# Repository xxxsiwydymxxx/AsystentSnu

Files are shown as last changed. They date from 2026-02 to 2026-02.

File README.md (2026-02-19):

Author: Piotr Szlejter
Project name: Asystent snu, urządzenie mierzące czynniki wpływające na sen
Description:
Urządzenie składa się z 2 części komunikujących się ze sobą bezprzewodowo
urządzenie bazowe posiada czujniki temperatury, ciśnienia atmosferycznego, 
wilgotności powietrza, dodatkowo zawiera czujnik ruchu i mikrofon, dodatkowo
 urządzenie posiada wyświetlacz / możliwość połączenia się z telefonem, 
 dodatkowo urządzenie może posiadać głośnik.
	Urządzenie dodatkowe jest zakładane na nadgarstek/palec i posiada 
pulsometr, oraz czujnik nasycenia krwi tlenem.
	Działanie: urządzenie wykonuje pomiary podczas snu i wyświetla je 
na wyświetlaczu oraz zapisuje do pamięci, dodatkowo urządzenie może 
odtwarzać biały szum przez wbudowany głośnik

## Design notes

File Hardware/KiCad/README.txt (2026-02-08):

Schematy zostały wykonane w programie KiCAD

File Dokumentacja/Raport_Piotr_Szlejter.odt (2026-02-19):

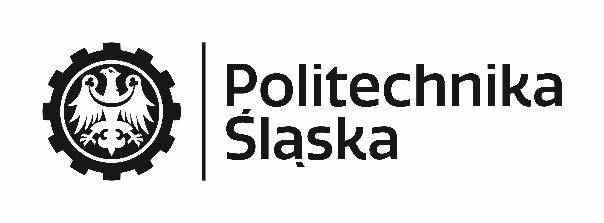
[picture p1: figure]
Obraz zawierający tekst, Czcionka, logo, Grafika Zawartość wygenerowana przez AI może być niepoprawna.
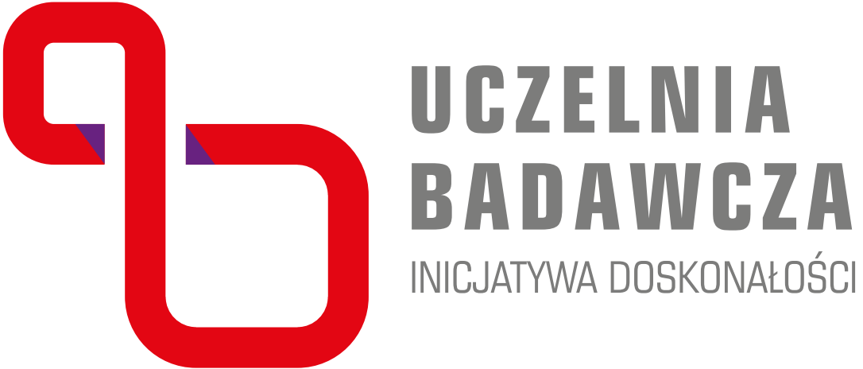
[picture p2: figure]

Raport
Rodzaj zajęć
Projekt
Przedmiot
Systemy Mikroprocesorowe i Wbudowane
Rok akademicki | | Miasto | Kierunek | | Semestr | Prowadzący | | Grupa | Sekcja
2025/2026 | | G | Inf | | 5 | GB | | 5 | 9
Planowany termin wykonywania ćwiczenia | | | | Faktyczny termin wykonania ćwiczenia
Data | | Godzina | | Data | | | Godzina
26.01.2026 | | 11:30-13:00 | | 26.01.2026 | | | 11:30-13:00
Numer ćwiczenia | Temat ćwiczenia
| Projekt – Asystent Snu

Skład sekcji
| Imię i nazwisko | Uwagi
1 | Piotr Szlejter
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
1. Temat Projektu:

Asystent Snu – urządzenie mierzące czynniki wpływające na sen.

2. Linki do repozytorium:

- https://drive.google.com/drive/folders/1vB9gLUQ3DNj9q-B88YDbHVIixlTGyozg?usp=sharing

-https://github.com/xxxsiwydymxxx/AsystentSnu.git

3. Opis założeń projektu:

- Urządzenie mierzące czynniki mające wpływ na sen.

- Urządzenie składa się z stacji bazowej, oraz nakładanego na palec, bezprzewodowego urządzenia – czujnika.

- Urządzenie mierzy: temperaturę, ciśnienie atmosferyczne, wilgotność powietrza, puls, poziom natężenia tlenu w krwi.

- Urządzenie wyświetla na bieżąco zmierzone wartości i zapisuje je na kartę microSD ze znacznikiem czasowym.

- Zestaw składa się z 2 urządzeń łączących się bezprzewodowo, zasilanie głównego urządzenia za pomocą kabla USB, urządzenia dodatkowego za pomocą akumulatora z możliwością podłączenia go do ładowania.

- Urządzenie dodatkowe zasilane przez akumulator przez czas przynajmniej 10 godzin.

- Urządzenie dodatkowe ma możliwość podłączenia do ładowania.

- Urządzenie dodatkowe ma możliwość wyłączenia się w celu nie zużywania energii.

- Urządzenie dodatkowe przesyła do urządzenia głównego rezultaty pomiarów pulsu i nasycenia tlenem krwi.

4. Analiza zadania:

Potrzebne były 2 mikrokontrolery, pełniące funkcję jednostki głównej, przetwarzającej pomiary i komunikujące się ze sobą. Ze względu na energooszczędność względem Wi-fi, i to że urządzenia będą współpracować ze sobą w obrębie jednego pomieszczenia wybrane zostały urządzenia posiadające moduł BLE – Bluetooth low energy.
Czujniki zostały dobrane tak, aby w rozsądnej kwocie mierzyły jak najwięcej czynników mogących mieć wpływ na sen.

Urządzenie dodatkowe powinno być zasilane z baterii aby ograniczyć możliwość zerwania kabla w trakcie snu, gdy czujnik przymocowany jest do palca.

4. Wybrane podzespoły:

a) urządzenie główne:

- mikrokontroler: Raspberry PI pico 2 w, wybrane z powodu niskiej ceny, możliwości Bluetooth / Wi-fi, wysokiej wydajności mikrokontrolera.

- czujniki: czujnik bme280: niska cena, możliwości pomiaru wilgotności, ciśnienia atmosferycznego oraz temperatury na jednym module.

- wyświetlacz OLED: Waveshare zgodny z sterownikiem ssd1306: wyświetlacz jest dość czytelny dla małej ilości danych, oraz był już dostępny w zasobach własnych.

- czytnik kart microSD: najtańszy model dostępny w sklepie Botland komunikujący się przez SPI.

- Moduł RTC: HW-111: moduł pozwoli na zapisywanie danych na kartę microSD ze znacznikiem czasowym.

b) urządzenie dodatkowe:

- mikrokontroler: Seeed xiao NRF52840: wybrany ze względu na wbudowaną ładowarkę baterii, możliwości łączenia się przez bluetooth, oraz niski pobór mocy.

- czujnik tętna: M5stack heart MAX30100: wybrany ze względu na gotową obudowę i możliwość odczytu tętna i nasycenia tlenem krwi.

- akumulator li-pol akyga 900 mAh

5. Specyfikacja wewnętrzna:

a) Schematy blokowe i ideowe

- urządzenie główne schemat blokowy:

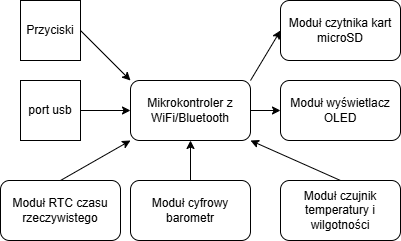
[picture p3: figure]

- urządzenie główne schemat ideowy:

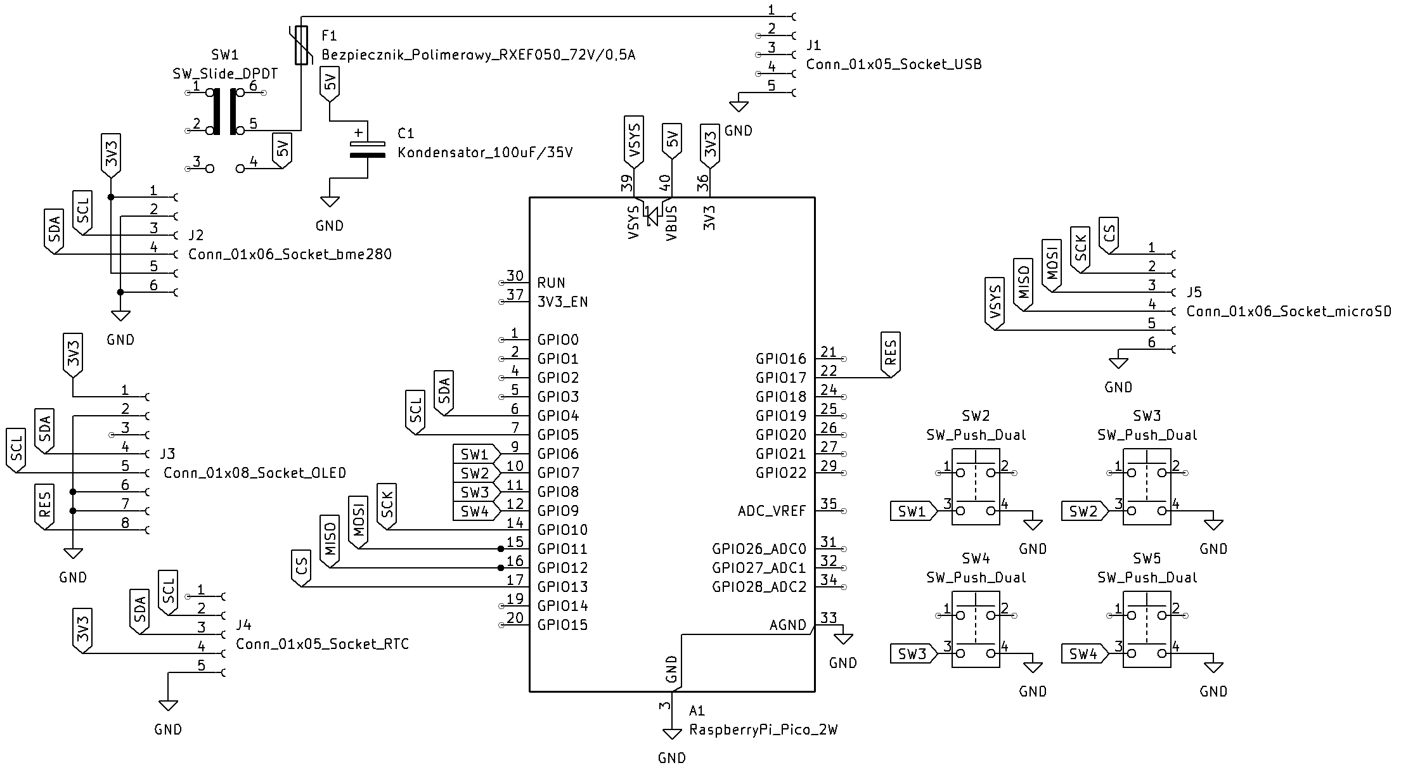
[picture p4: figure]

- urządzenie dodatkowe schemat blokowy:

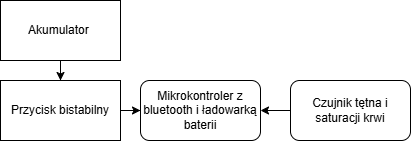
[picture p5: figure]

- urządzenie dodatkowe schemat ideowy:

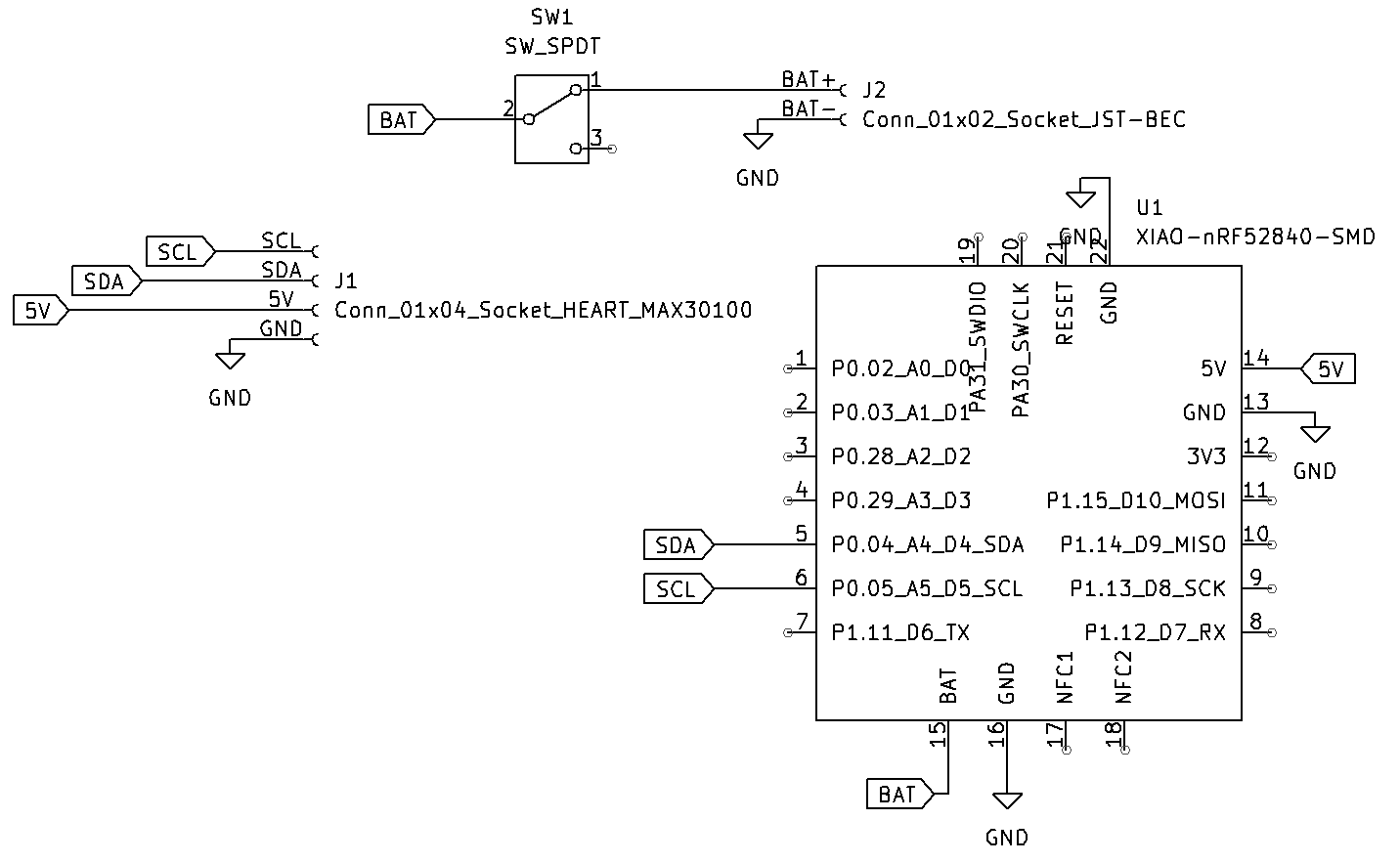
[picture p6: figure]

b) Opis funkcji poszczególnych bloków układu:

- urządzenie główne:

Blok Przyciski: przyciski tactile switch podłączone od portu do masy.

Blok port USB: zewnętrzny port USB pozwalający dostarczyć zasilanie, z możliwością wyłączenia urządzenia przyciskiem.

Blok mikrokontrolera: mikrokontroler Raspberry pi pico 2w, zasilany przez pin Vbus z portu USB.

Blok moduł RTC: moduł RTC z baterią CR2032, dzięki baterii przechowuje zapisany czas przy wyłączonym urządzeniu, baterię należy wymienić co ok 10 lat.

Blok moduł czytnika kart microSD: połączony przez SPI moduł pozwalający dołączyć kartę microSD sformatowaną w formacie fat32.

Blok moduł wyświetlacz OLED: wyświetlacz z możliwością komunikowania się przez i2c lub SPI, skonfigurowany przez przelutowanie rezystora na komunikację po i2c. Wymaga podłączenia pinu reset do portu GPIO mikrokontrolera.

Blok moduł czujnik temperatury i wilgotności: moduł BME280, komunikuje się przez i2c. Wynik ciśnienia atmosferycznego nie jest ustandaryzowany do poziomu morza.

- urządzenie dodatkowe:

Blok mikrokontrolera: Seeed Xiao NRF52840, energooszczędny mikrokontroler, mogący komunikować się poprzez bluetooth, do jego pinów BAT+ i BAT- przylutowany został przewód do akumulatora/

Blok czujnik tętna i saturacji krwi: m5stack heart max 30100, czujnik działa przez podświetlenie diodą podczerwoną palca, lub nadgarstka, i przez czujnik monitorujące tętno i saturację tlenem krwi. Aby mierzyć tętno w nadgarstku trzeba konfigurując czujnik, ustawić zasilanie diody na większe niż domyślne 7,6 mA dla palca, ponieważ nie wystarcza wtedy światła aby przebić skórę. Dla palca natomiast ustawienie 7.6 mA w zupełności wystarcza i większy prąd powoduje że czujnik jest przejaskrawiony i niepoprawnie odczytuje pomiar.

c) Schemat montażowy obejmujący projekt płytki drukowanej, rozmieszczenie elementów na płytce, rozmieszczenie elementów urządzenia w obudowie:

- urządzenie główne:

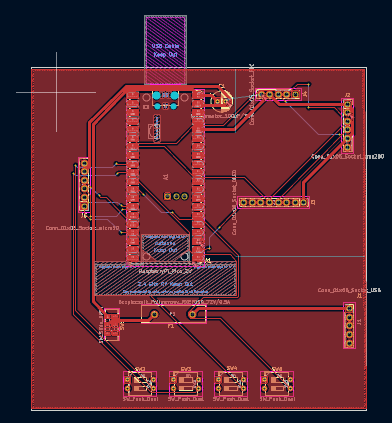
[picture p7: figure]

- urządzenie dodatkowe nie wymaga płytki drukowanej ponieważ składa się jedynie z mikrokontrolera, gotowego przyłącza baterii na nim i 1 czujnika z gotową obudową.

d) Algorytm oprogramowanie urządzenia:

- urządzenie główne:

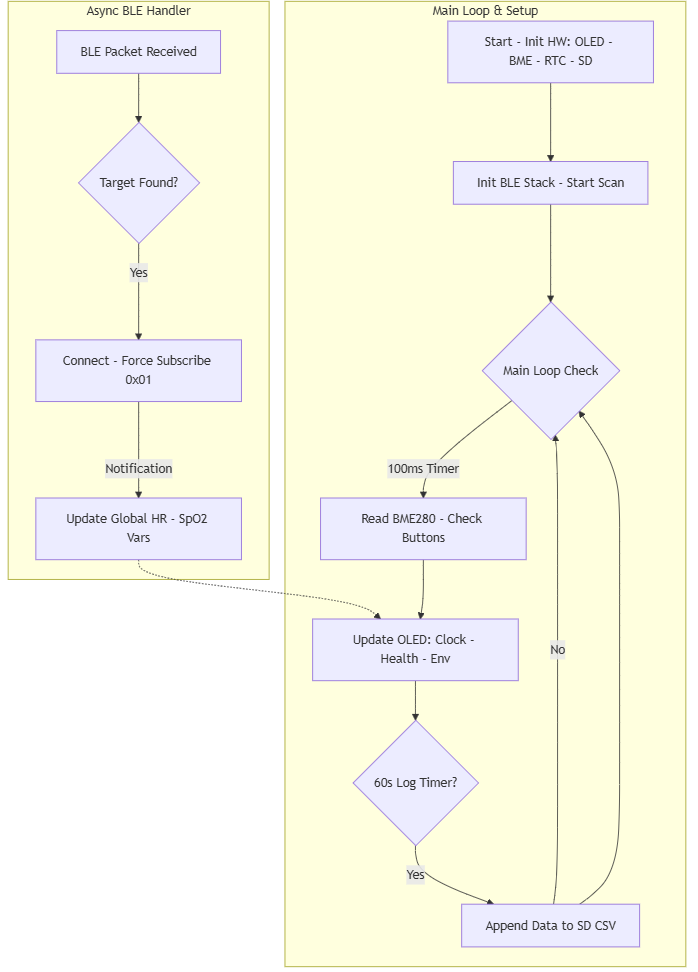
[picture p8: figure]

- urządzenie dodatkowe:

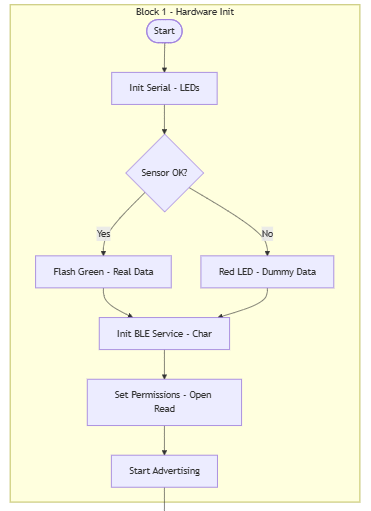
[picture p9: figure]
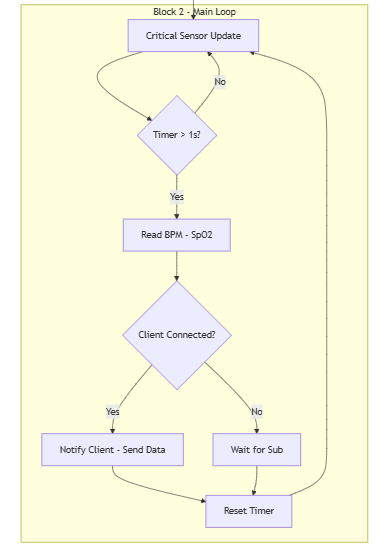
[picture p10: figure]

e) Opis wszystkich zmiennych:

- urządzenie główne:

zmienne potrzebne dla bluetooth:

const char* target_name = "XIAO_Health_Native";

const uint16_t target_service_uuid = 0xFF00;

const uint16_t target_char_uuid = 0xFF01;

static btstack_packet_callback_registration_t hci_event_callback_registration;

static hci_con_handle_t connection_handle = HCI_CON_HANDLE_INVALID;

static gatt_client_notification_t notification_listener;

static gatt_client_service_t found_service;

static gatt_client_characteristic_t found_char;

static bool service_found = false;

static bool char_found = false;

static bool is_subscribed = false;

zmienne potrzebne dla wyświetlania wartości przesłanych przez bluetooth:

volatile int global_hr = 0;

volatile int global_spo2 = 0;

bool bleConnected = false;

zmienne potrzebne dla podłączonych czujników, wyświetlacza i przycisków:

// --- HARDWARE SETTINGS ---

// 1. I2C

#define I2C_SDA_PIN 4

#define I2C_SCL_PIN 5

#define OLED_RESET 17

// 2. SPI1

#define SD_SCK 10

#define SD_MOSI 11

#define SD_MISO 12

#define SD_CS 13

// 3. BUTTONS

#define BTN1_PIN 6

#define BTN2_PIN 7

#define BTN3_PIN 8

#define BTN4_PIN 9

#define BME_ADDR 0x76

#define OLED_ADDR 0x3C

Adafruit_SSD1306 display(128, 64, &Wire, OLED_RESET);

Adafruit_BME280 bme;

RTC_DS3231 rtc;

uint32_t tsLastReport = 0;

uint32_t tsLastLog = 0;

const long REPORT_PERIOD = 100;

const long LOG_PERIOD = 60000;

bool sdStatus = false;

int currentMode = 1;

- urządzenie dodatkowe:

wbudowane LED:

#define LEDR 11

#define LEDG 12

#define LEDB 13

zmienne przechowujące dane z czujnika:

PulseOximeter pox;

uint32_t tsLastReport = 0;

bool sensorWorking = false;

zmienne potrzebne dla bluetooth:

const uint16_t CUSTOM_SERVICE_UUID = 0xFF00;

const uint16_t CUSTOM_CHAR_UUID = 0xFF01;

BLEService customService = BLEService(CUSTOM_SERVICE_UUID);

BLECharacteristic customChar = BLECharacteristic(CUSTOM_CHAR_UUID);

f) Opis funkcji wszystkich procedur:

- urządzenie główne:

void setup();

Funkcja inicjalizuje oprogramowanie.

void loop();

Główna pętla programu.

void logData(DateTime dt, float t, float h, float p, int hr, int spo2);

Funkcja logujące dane do karty microSD

void updateScreen(DateTime now, float t, float h, float p, bool sdOk, int mode);

Funkcja wyświetlająca dane na wyświetlacz OLED.

static void packet_handler(uint8_t packet_type, uint16_t channel, uint8_t *packet, uint16_t size);

Jest to główna funkcja zarządzająca stanami Bluetooth, która odpowiada za skanowanie otoczenia, łączenie się z wykrytym urządzeniem "XIAO_Health_Native" oraz ponowne uruchamianie skanowania po rozłączeniu .

static void gatt_event_handler(uint8_t packet_type, uint16_t channel, uint8_t *packet, uint16_t size);

Funkcja ta odbiera przychodzące powiadomienia - notyfikacje z danymi i wpisuje odebrane wartości tętna oraz SpO2 do zmiennych globalnych .

static void on_characteristics_discovered(uint8_t packet_type, uint16_t channel, uint8_t *packet, uint16_t size);

Weryfikuje znalezienie szukanej charakterystyki - 0xFF01 i po jej wykryciu wymusza subskrypcję powiadomień poprzez ręczny zapis wartości 0x01 do deskryptora .

static void on_services_discovered(uint8_t packet_type, uint16_t channel, uint8_t *packet, uint16_t size);

Sprawdza, czy połączone urządzenie posiada właściwą usługę – 0xFF00 i jeśli tak, uruchamia proces wyszukiwania w niej charakterystyk .

- urządzenie dodatkowe:

void onBeatDetected()

Funkcja załączający LEDy po wykryciu tętna.

void setup()

Funkcja inicjalizująca.

void loop()

Główna pętla programu.

g) Opis interakcji oprogramowania z układem elektronicznym:

- urządzenie główne:

Oprogramowanie steruje magistralą I2C w celu inicjalizacji i komunikacji z wyświetlaczem OLED oraz czujnikami środowiskowymi BME280 i modułem czasu rzeczywistego DS3231 . Kod cyklicznie monitoruje cyfrowe wejścia podłączone do czterech przycisków fizycznych i na ich podstawie zmienia tryb prezentacji danych na ekranie . System zarządza również magistralą SPI do obsługi karty pamięci SD na której regularnie zapisuje logi z danymi pomiarowymi w pliku tekstowym . Równolegle stos Bluetooth Low Energy pracuje w trybie centralnym skanując otoczenie w poszukiwaniu czujnika medycznego i po nawiązaniu połączenia odbiera od niego pakiety danych .

- urządzenie dodatkowe:

Program obsługuje czujnik pulsoksymetru MAX30100 poprzez magistralę I2C i wykonuje w głównej pętli krytyczne czasowo operacje przetwarzania sygnału biometrycznego. Mikrokontroler steruje diodami LED RGB sygnalizując kolorem zielonym poprawną pracę sensora lub czerwonym błąd inicjalizacji i przejście w tryb generowania danych testowych . Oprogramowanie uruchamia stos Bluetooth w trybie peryferyjnym rozgłaszając dedykowaną usługę i po otrzymaniu żądania subskrypcji wysyła do urządzenia nadrzędnego powiadomienia z aktualnym tętnem i nasyceniem tlenem .

h) Szczegółowy opis ważniejszych procedur:

- urządzenie główne:

static void packet_handler(uint8_t packet_type, uint16_t channel, uint8_t *packet, uint16_t size);

Jest to główna funkcja zarządzająca stanami Bluetooth, która odpowiada za skanowanie otoczenia, łączenie się z wykrytym urządzeniem "XIAO_Health_Native" oraz ponowne uruchamianie skanowania po rozłączeniu .

static void gatt_event_handler(uint8_t packet_type, uint16_t channel, uint8_t *packet, uint16_t size);

Funkcja ta odbiera przychodzące powiadomienia - notyfikacje z danymi i wpisuje odebrane wartości tętna oraz SpO2 do zmiennych globalnych .

static void on_characteristics_discovered(uint8_t packet_type, uint16_t channel, uint8_t *packet, uint16_t size);

Weryfikuje znalezienie szukanej charakterystyki - 0xFF01 i po jej wykryciu wymusza subskrypcję powiadomień poprzez ręczny zapis wartości 0x01 do deskryptora .

static void on_services_discovered(uint8_t packet_type, uint16_t channel, uint8_t *packet, uint16_t size);

Sprawdza, czy połączone urządzenie posiada właściwą usługę – 0xFF00 i jeśli tak, uruchamia proces wyszukiwania w niej charakterystyk .

- urządzenie dodatkowe:

void loop()
Główna pętla programu nieustannie wywołuje metodę aktualizacji obiektu pulsoksymetru o ile flaga stanu sensora jest aktywna co pozwala na precyzyjne śledzenie uderzeń serca w czasie rzeczywistym. Co jedną sekundę kod sprawdza licznik czasu i pobiera bieżące wartości tętna oraz nasycenia krwi tlenem lub w przypadku awarii sprzętu podstawia sztywne wartości testowe wynoszące odpowiednio 65 BPM i 98 procent . Następnie procedura weryfikuje stan połączenia Bluetooth i jeśli klient jest połączony oraz aktywował subskrypcję powiadomień to wysyła dwubajtowy pakiet danych do urządzenia centralnego . W przypadku braku aktywnej subskrypcji lub po wysłaniu danych program wypisuje odpowiednie komunikaty diagnostyczne na port szeregowy i resetuje licznik czasu w celu odmierzenia kolejnego cyklu pomiarowego .

5. Specyfikacja zewnętrzna:

a) Opis funkcji elementów sterujących urządzeniem:

- urządzenie główne:

Przyciski tactile switch przełączają urządzenie między czterema różnymi wyświetlanymi ekranami, na 1 znajduje się data i godzina, na 2 znajdują się pomiary z urządzenia dodatkowego przesłane przez bluetooth, na 3 znajdują się wszystkie pomiary na jednym ekranem łącznie z temperaturą, wilgotnością i ciśnieniem, na 4 ekranie nie wyświetla się nic, służy on jako zgaszony ekran i tylko zapisuje na kartę microSD w tle.

Przełącznik suwakowy pozwala na włączenie i wyłączenie urządzenia.

-urządzenie dodatkowe:

Przycisk bistabilny pozwala na włączenie i wyłączenie urządzenia, nie będzie on działał gdy urządzenie podłączymy przez port usb typu C do ładowania.

b) Opis funkcji elementów wykonawczych:

- urządzenie główne:

Wyświetlacz OLED wyświetla 4 różne ekrany opisane zawierające różne dane z czujników.

Moduł kart microSD pozwala na włożenie karty microSD, i zapisywanie na nią pomiarów wraz z znacznikiem czasowym z modułu RTC.

c) Opis reakcji oprogramowania na zdarzenia zewnętrzne:

- urządzenie główne:

Po włączeniu urządzenia wykonuje ono próbę połączenia się przez bluetooth, gdy w pobliżu znajduje się urządzenie dodatkowe włączone, to urządzenia nawiążą połączenie, następuje również inicjalizacja modułu kart microSD, jeśli się nie powiedzie wyświetli się na ekranie komunikat.

Po przyciśnięciu przycisku urządzenie reaguje przełączajać tryb pracy – zawartość wyświetlaną na ekranie.

- urządzenie dodatkowe:

urządzenie włączy się po przyciśnięciu przycisku bistabilnego, i zacznie propagację siebie w sieci bluetooth, sygnalizując to diodą LED, po połączeniu dioda LED zgaśnie, po przyłożeniu palca do czujnika m5stack Heart max 30100, dioda LED zapali się po wykryciu pulsu.

d) Skrócona instrukcja obsługi urządzenia:

Urządzenie główne należy włączyć do zasilania 5V min 1A przez port micro USB dodatkowy z boku urządzenia, nie ten wbudowany w Raspberry pi pico 2w, po włączeniu można wybrać tryb pracy przyciskając odpowiedni przycisk.

Urządzenie dodatkowe należy wyłączać przyciskiem bistabilnym, można je również podłączyć do ładowania przez wbudowany w Seeed Xiao port USB typu C.

Aby połączyć urządzenia należy najpierw włączyć urządzenie dodatkowe, a później włączyć urządzenie główne, połączenie nastąpi automatycznie.

6. Opis montażu i uruchamiania:

a) Jakie problemy wystąpiły podczas montażu i uruchamiania i jak zostały rozwiązane.

- Problem z wyświetlaczem OLED: wyświetlacz OLED zdawał się nie działać, nie wyświetlał nic, po podłączeniu pinu RES z wyświetlacza do portu GPIO pico i odpowiedniej obsłudze programowej wyświetlacz zaczął działać

- Problemy z połączeniem bluetooth, urządzenie główne z raspberry pi pico 2 w, zdawało się nie działać, łączyło się po bluetooth ale nie pobierało danych przesyłanych, podobnie po skonfigurowaniu jako serwer i połączeniu po bluetooth z telefonem, testowano z użyciem apki NRF connect, nie transmitowało danych. Problem występował przy użyciu bilbioteki bluetooth Adafruit. Problem został rozwiązany po przejściu na wspieraną przez raspberry pi pico bibliotekę bluetooth btstack.h

- Głównym problemem była niemożność automatycznego odnalezienia przez Pico właściwego adresu sterującego w pamięci Bluetooth urządzenia XIAO. Standardowa funkcja biblioteki BTstack gubiła się przy próbie zapisu do deskryptora konfiguracji, co uniemożliwiało włączenie powiadomień o nowych danych. Dodatkowo kod na XIAO miał zbyt restrykcyjne ustawienia uprawnień, które blokowały próby zapisu ze strony niesparowanego urządzenia takiego jak Pico. Skutkowało to sytuacją, w której XIAO próbowało wysyłać dane w próżnię otrzymując błąd transmisji, podczas gdy Pico czekało w nieskończoność na potwierdzenie subskrypcji. Rozwiązanie polegało na obejściu automatycznego wyszukiwania i ręcznym wyliczeniu adresu sterującego poprzez dodanie jedynki do adresu charakterystyki głównej. Dzięki temu mogliśmy wysłać surową komendę aktywacyjną bezpośrednio pod wskazany adres ignorując standardowe procedury negocjacji. Równocześnie zmodyfikowaliśmy kod nadajnika, aby zezwalał na otwarty dostęp do zapisu i wstrzymywał wysyłanie pomiarów do momentu poprawnego zestawienia połączenia.

b) Jakie przeprowadzono testy poprawności działania urządzenie:

Przeprowadzono testy łączności w obrębie jednego pomieszczenia, przeprowadzono testy poszczególnych komponentów łącząc je tylko z mikrokontrolerem i wgrywając testowy kod.

Przeprowadzono obszerne testy łączności bluetooth z różnymi wersjami kodu łączacymi się z telefonem – aplikacją NRF Connect, lub ze sobą i wypisujące na Serial monitor.

7. Wnioski z uruchamiania i testowania:

- Podczas testowania wyszedł problem w urządzeniu dodatkowym polegający na tym że urządzenie dodatkowe po zasileniu z baterii 3,7 V, nie ustawia zasilania 5v na pinie 5V, przez co urządzenie m5stack Heart max 30100 nie włączało się ponieważ mimo logiki 3,3V urządzenie to jest zasilane z 5V, problem ten można by rozwiązać kupując droższy czujnik oparty na module max 30102, pracujący na zasilaniu 3,3 V. Rozwiązano ten problem przez zasilenie urządzenia przez kabel usb z powerbanka, niestety powoduje to konieczność użycia kabla, i lepszym rozwiązaniem byłoby kupienie droższego czujnika, ponieważ mógłby on być uruchomiony przy zasilaniu z baterii.

- Kluczowym wyzwaniem programistycznym okazała się obsługa stosu Bluetooth Low Energy na mikrokontrolerze Raspberry Pi Pico 2 W który miał problemy z automatycznym wykrywaniem deskryptorów urządzenia podrzędnego

-W obecnej konfiguracji część mobilna wymaga zasilania przewodowego USB co ogranicza komfort użytkowania podczas snu i wymusza w przyszłości wymianę sensora na model kompatybilny z napięciem 3.3V

- Mimo problemów z zasilaniem zrealizowano główny cel projektu jakim jest integracja pomiarów środowiskowych i biometrycznych oraz ich archiwizacja na karcie microSD z wykorzystaniem znacznika czasu .

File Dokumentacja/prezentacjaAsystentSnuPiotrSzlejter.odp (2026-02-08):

## Asystent Snu

Projekt - Systemy Mikroprocesorowe i Wbudowane

## Projekt Asystent Snu

- Urządzenie mierzące czynniki mające wpływ na sen.
- Urządzenie składa się z stacji bazowej, oraz nakładanego na palec, bezprzewodowego urządzenia - czujnika

## Założenia projektowe

- Urządzenie mierzy: temperaturę, ciśnienie atmosferyczne, wilgotność powietrza, puls, poziom natężenia tlenu w krwi.
- Urządzenie wyświetla na bieżąco zmierzone wartości i zapisuje je na kartę microSD ze znacznikiem czasowym.
- Zestaw składa się z 2 urządzeń łączących się bezprzewodowo, zasilanie głównego urządzenia za pomocą kabla USB, urządzenia dodatkowego za pomocą akumulatora z możliwością podłączenia go do ładowania.

## Założenia – urządzenie dodatkowe

- Urządzenie zasilane przez akumulator przez czas przynajmniej 10 godzin.
- Urządzenie ma możliwość podłączenia do ładowania.
- Urządzenie ma możliwość wyłączenia się w celu nie zużywania energii.
- Urządzenie przesyła do urządzenia głównego rezultaty pomiarów pulsu i nasycenia tlenem krwi.

## Schematy blokowe

## Schemat blokowy – urządzenie główne

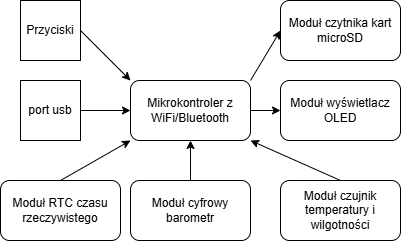
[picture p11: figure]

## Schemat blokowy – urządzenie dodatkowe


## Wybór komponentów

## Urządzenie główne

- Mikrokontroler – Raspberry Pi pico 2 W
- Czujnik wilgotności, temperatury ciśnienia – BME280
- Wyświetlacz OLED 128x64px SSD1306 – Waveshare 9092
- Moduł RTC I2C – HW-111

## Urządzenie dodatkowe

- Mikrokontroler – Seeed Xiao BLE nRF52840.
- Czujnik tętna i saturacji krwi – M5Stack Heart MAX30100.
- Akumulator – Li-Pol Akyga 900 mAh 3,7V złącze JST-BEC.

## Dobór akumulatora

- Założenie – przynajmniej 10h pracy na akumulatorze.
- Suma szczytowych poborów mocy: 90-150 mA.
- 90*10h, 150 * 10h.
- Wynik: od 900 mAh do 1500 mAh.

## Schematy ideowe

## Urządzenie główne

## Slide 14


## Urządzenie dodatkowe

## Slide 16


## Płytka drukowana

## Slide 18


## Kosztorys

## Urządzenie główne

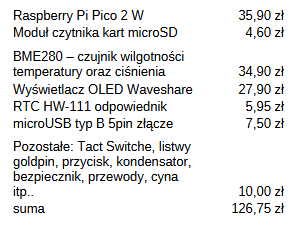
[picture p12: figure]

## Urządzenie dodatkowe

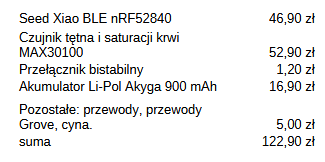
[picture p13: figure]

## Kosztorys

## Wnioski

- Urządzenie dodatkowe zawiera tylko niezbędne elementy: akumulator, czujniki biometryczne i mikrokontroler z łącznością bluetooth. Dzięki temu opaska może być mniejsza i działać dłużej na baterii.
- Urządzenie główne przejmuje cięższe zadania. Obsługuje WiFi, zapis danych na kartę SD, wyświetlacz OLED oraz pomiary środowiskowe. Dzięki czemu mamy więcej danych o czynnikach wpływających na sen.

## Wnioski

- Koszt urządzenia wyniósł prawie 250 zł co jest dość dużą kwotą, można oszczędzić na urządzeniu kupując je hurtowo, a nie poprzez detaliczny sklep Botland.
- Dalsze usprawnienie urządzenia można zrealizować poprzez zamianę czujnika bme280 na droższy bme680, lub poprzez dodanie np.. czujników VOC, lub czujniki pyłów.

## Dziękuję za uwagę

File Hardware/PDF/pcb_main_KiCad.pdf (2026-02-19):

19.02.2026, 04:02 | pcb.PNG (392×423)


file:///C:/Users/HP/Desktop/polsl/SMiW/projekt/różne/pcb.PNG | 1/1

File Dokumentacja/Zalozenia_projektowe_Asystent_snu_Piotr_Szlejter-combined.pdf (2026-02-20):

`

| Katedra Grafiki Wizji Komputerowej i Systemów Cyfrowych | RAu6
Rok akademicki: | Rodzaj studiów*: SSI/NSI/NSM | Przedmiot (J zyki ę Asemblerowe/SMiW): | Grupa | Sekcja
2025/202 6 | SSI | SMiW | 5 | 9
Imi : ę Nazwisko: | Piotr | Prowadz cy ą : OA/JP/KT/GD/ GB/KH/AO | GB
| Szlejter

# Karta projektu SMIW

Temat projektu:

Asystent snu – urządzenie mierzące czynniki wpływające na sen

Główne zało enia projektu: ż

Urządzenie składa się z 2 części komunikujących się ze sobą bezprzewodowo urządzenie bazowe posiada czujniki temperatury, ciśnienia atmosferycznego, wilgotności powietrza, dodatkowo zawiera czujnik ruchu i mikrofon, dodatkowo urządzenie posiada wyświetlacz / możliwość połączenia się z telefonem, dodatkowo urządzenie może posiadać głośnik.
Urządzenie dodatkowe jest zakładane na nadgarstek/palec i posiada pulsometr, oraz czujnik nasycenia krwi tlenem.
Działanie: urządzenie wykonuje pomiary podczas snu i wyświetla je na wyświetlaczu oraz zapisuje do pamięci, dodatkowo urządzenie może odtwarzać biały szum przez wbudowany głośnik

Temat: Asystent Snu – urządzenie mierzące czynniki wpływające na sen
Autor: Piotr Szlejter

Założenia: Urządzenie składa się z 2 części komunikujących się ze sobą bezprzewodowo urządzenie bazowe posiada czujniki temperatury, ciśnienia atmosferycznego, wilgotności powietrza, dodatkowo zawiera czujnik ruchu i mikrofon, jak również wyświetlacz / możliwość połączenia się z telefonem. Do zapisywania pomiarów i nagrań dźwięku urządzenie będzie posiadać moduł czytnika kart microSD, wraz z kartą microSD.
Urządzenie dodatkowe jest zakładane na nadgarstek/palec i posiada pulsometr, oraz czujnik nasycenia krwi tlenem i jest zasilane akumulatorem aby nie było wystąpiła sytuacja zerwania kabla mimowolnym ruchem podczas snu.

Schemat głównego urządzenia:

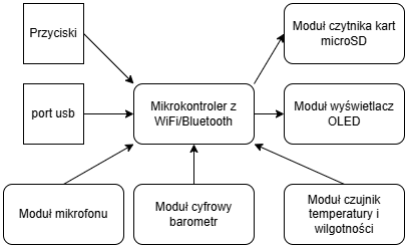
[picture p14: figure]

Schemat urządzenia dodatkowego:

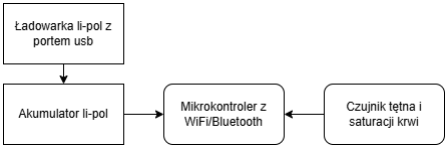
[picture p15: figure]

Mikrokontroler: Po dokonaniu rozpoznania na rynku, zdecydowałem się na użycie mikrokontrolera Raspberry Pi Pico 2 W, ze względu na jego niską cenę, możliwości WiFi/Bluetooth, oraz szerokie wsparcie producenta i społeczność internetową.

Zasilanie urządzenia głównego: zasilanie odbędzie się poprzez port USB, zasilaczem może być ładowarka do telefonu, lub komputer potrafiący dostarczyć 5V 1A.

Zużycie zasilania (maksymalny pobierany prąd):
Komponent: | Maksymalne zużycie prądu [mA]:
Raspberry Pi Pico 2 W | 300

Wyświetlacz OLED | 25
Czujnik temperatury i wilgotności - Sensirion SHT40 | 0,0004
BMP280 - cyfrowy barometr | 0,0027
czytnik kart microSD - Waveshare 3947 | 200
Moduł z mikrofonem LM393 M5stack | 23,53
Razem: | 548,53

Łączne maksymalny prąd pobierany(525 mA) nie przekracza maksymalnego prądu jaki jest w stanie dostarczyć zasilacz USB (5V 1A).

Zasilanie urządzenia dodatkowego: Zasilanie urządzenia dodatkowego będzie zrealizowane przez akumulator li-pol.

Zużycie zasilania (maksymalny pobierany prąd):

Komponent: | Maksymalne zużycie prądu [mA]:
Raspberry Pi Pico 2 W | 300
Czujnik tętna i saturacji krwi MAX30100 | 0,6
| 300,6

Obliczenia pojemności akumulatora: Typowy pobór prądu przez Raspberry Pi Pico 2 W przy używaniu WiFi to 90–150 mA co oznacza że żeby bateria wytrzymała użycie przez 10h należy wybrać akumulator o pojemności:
od 90mA×10h=900mAh
do 150mA×10h=1500mAh

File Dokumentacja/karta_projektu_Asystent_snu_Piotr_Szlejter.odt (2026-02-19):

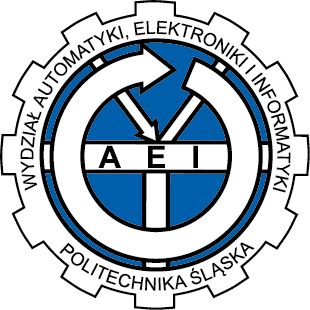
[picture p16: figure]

Katedra Grafiki Wizji Komputerowej i Systemów Cyfrowych RAu6 Rok akademicki: Rodzaj studiów*: SSI/NSI/NSM Przedmiot (Języki Asemblerowe/SMiW): Grupa Sekcja 2025/2026 SSI SMiW 5 9 Imię: Piotr Prowadzący: OA/JP/KT/GD/GB/KH/AO GB Nazwisko: Szlejter Karta projektu SMIW Temat projektu: Asystent snu – urządzenie mierzące czynniki wpływające na sen Główne założenia projektu: Urządzenie składa się z 2 części komunikujących się ze sobą bezprzewodowo urządzenie bazowe posiada czujniki temperatury, ciśnienia atmosferycznego, wilgotności powietrza, dodatkowo zawiera czujnik ruchu i mikrofon, dodatkowo urządzenie posiada wyświetlacz / możliwość połączenia się z telefonem, dodatkowo urządzenie może posiadać głośnik. Urządzenie dodatkowe jest zakładane na nadgarstek/palec i posiada pulsometr, oraz czujnik nasycenia krwi tlenem. Działanie: urządzenie wykonuje pomiary podczas snu i wyświetla je na wyświetlaczu oraz zapisuje do pamięci, dodatkowo urządzenie może odtwarzać biały szum przez wbudowany głośnik Data oddania: dd/mm/rrrr 19.02.2026 `

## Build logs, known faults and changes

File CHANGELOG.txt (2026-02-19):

Date: 19.02.2026

current_version
main: v2.5
secondary: v1.5

Version history:

Urządzenie główne:
v1.0
	test z modułem bme280
v1.1
	test z samym modułem RTC
v1.2
	test z modułem RTC i bme280
v1.3
	test z modułem microSD card
v1.4
	test z modułem heart max30100
v1.5
	test z mikrofonem
v1.6
	test z modułem bme280 i wyświetlaczem oled
v1.7
	test z modułami 280, oled, m5heart max30100
v1.8
	test z modułami bme 280, oled, microSD card
v1.9
	test z modułami bme 280, oled, microSD card, 4 switches
v2.0
	test BLE
v2.1
	test BLE z zamianą ról urządzeń
v2.2
	test połączenia z telefonem
v2.3
	test z biblioteką btstack.h
v2.4
	test z biblioteką ArduinoBLE z modułami bme280, oled, microSD card, RTC, 4 switch
v2.5
	test z biblioteką btstack.h z modułami oled, microSD card, bme280, RTC, 4 switch

Urządzenie dodatkowe:
v1.0
	test blink sketch
v1.2
	test blink z modułem heart m5stack max30100
v1.3
	test z ArduinoBLE
v1.4
	test połączenia z telefonem
v1.5
	test z ArduinoBLE z modułem m5stack heart max30100

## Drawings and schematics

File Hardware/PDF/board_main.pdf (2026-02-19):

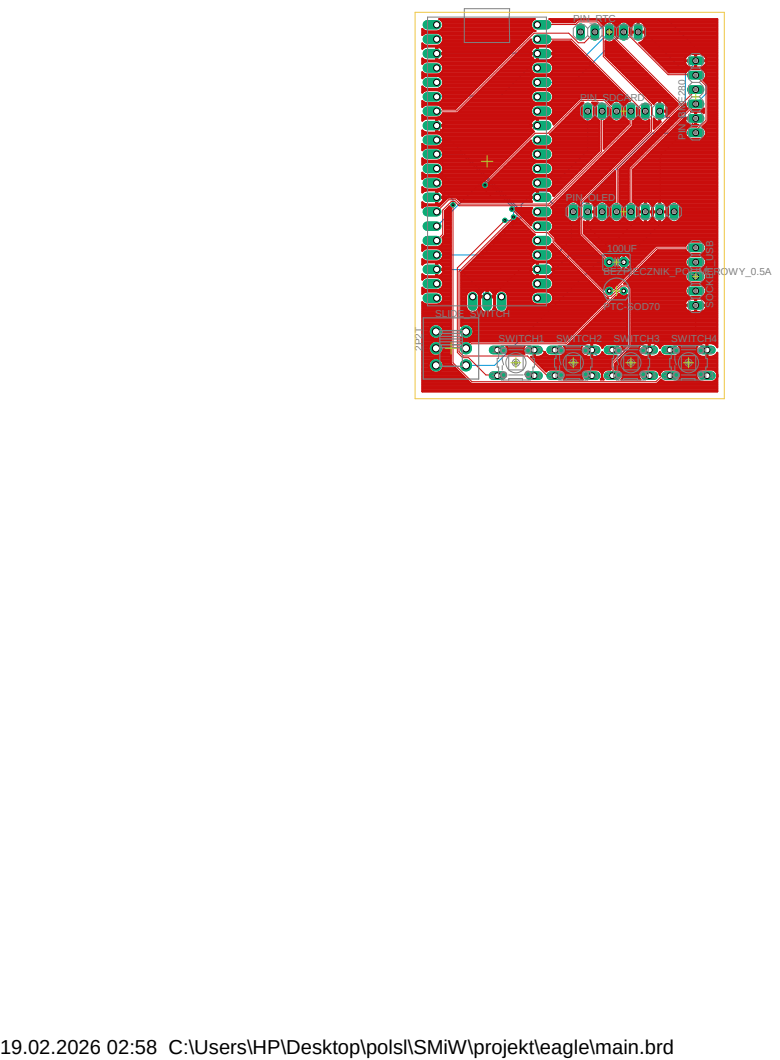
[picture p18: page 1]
BEZPIECZNIK_POLIMEROWY_0.5A PIN_BME²⁸⁰; PIN_OLED; PIN_RTC; PIN_SDCARD; SLIDE_SWITCH; SOCKET_USB; SWITCH1 SWITCH2 SWITCH3 SWITCH4; PTC-SOD70 2P²T

19.02.2026 02:58 C:\Users\HP\Desktop\polsl\SMiW\projekt\eagle\main.brd

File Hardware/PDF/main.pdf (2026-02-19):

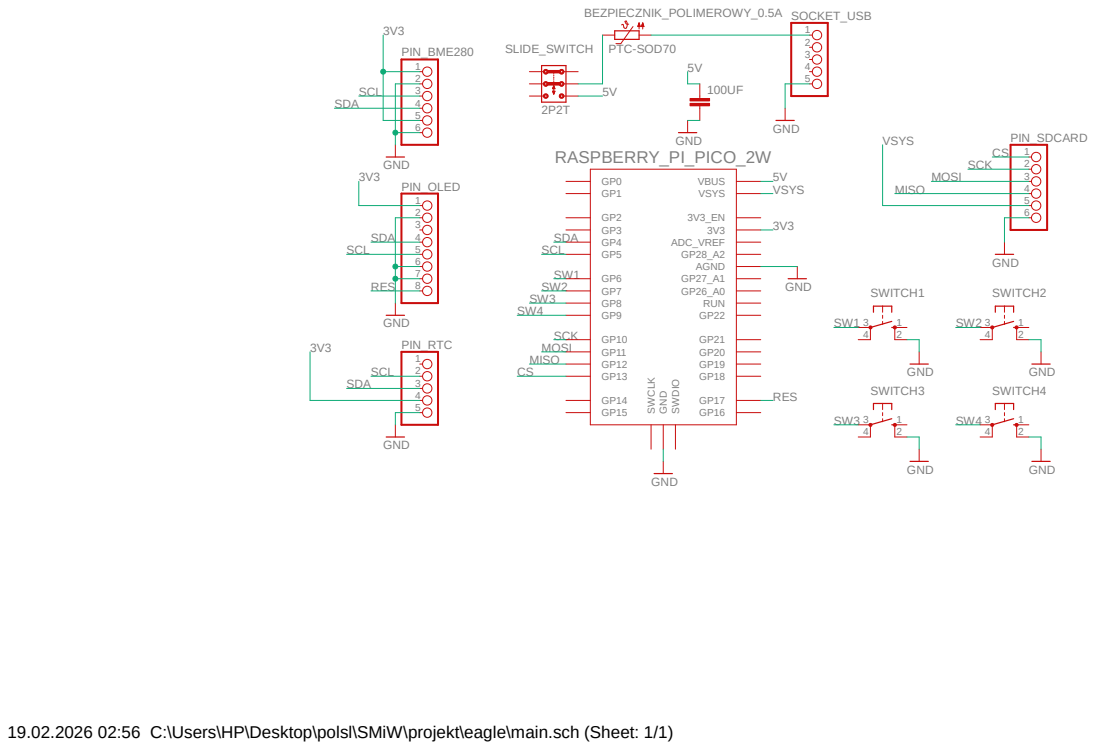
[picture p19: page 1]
GND; PTC-SOD70; RUN; AGND; ADC_VREF; VSYS; VBUS SWCLK GND SWDIO; RASPBERRY_PI_PICO_2W; 6 PIN_BME280; 8 PIN_OLED; 5 PIN_RTC; 6 PIN_SDCARD; SLIDE_SWITCH; 5 BEZPIECZNIK_POLIMEROWY_0.5A SOCKET_USB; 4 2 SWITCH1; 4 2 SWITCH2; 4 2 SWITCH3; 4 2 SWITCH4; SDA; SCL; SCK; MOSI; MISO; RES

19.02.2026 02:56 C:\Users\HP\Desktop\polsl\SMiW\projekt\eagle\main.sch (Sheet: 1/1)

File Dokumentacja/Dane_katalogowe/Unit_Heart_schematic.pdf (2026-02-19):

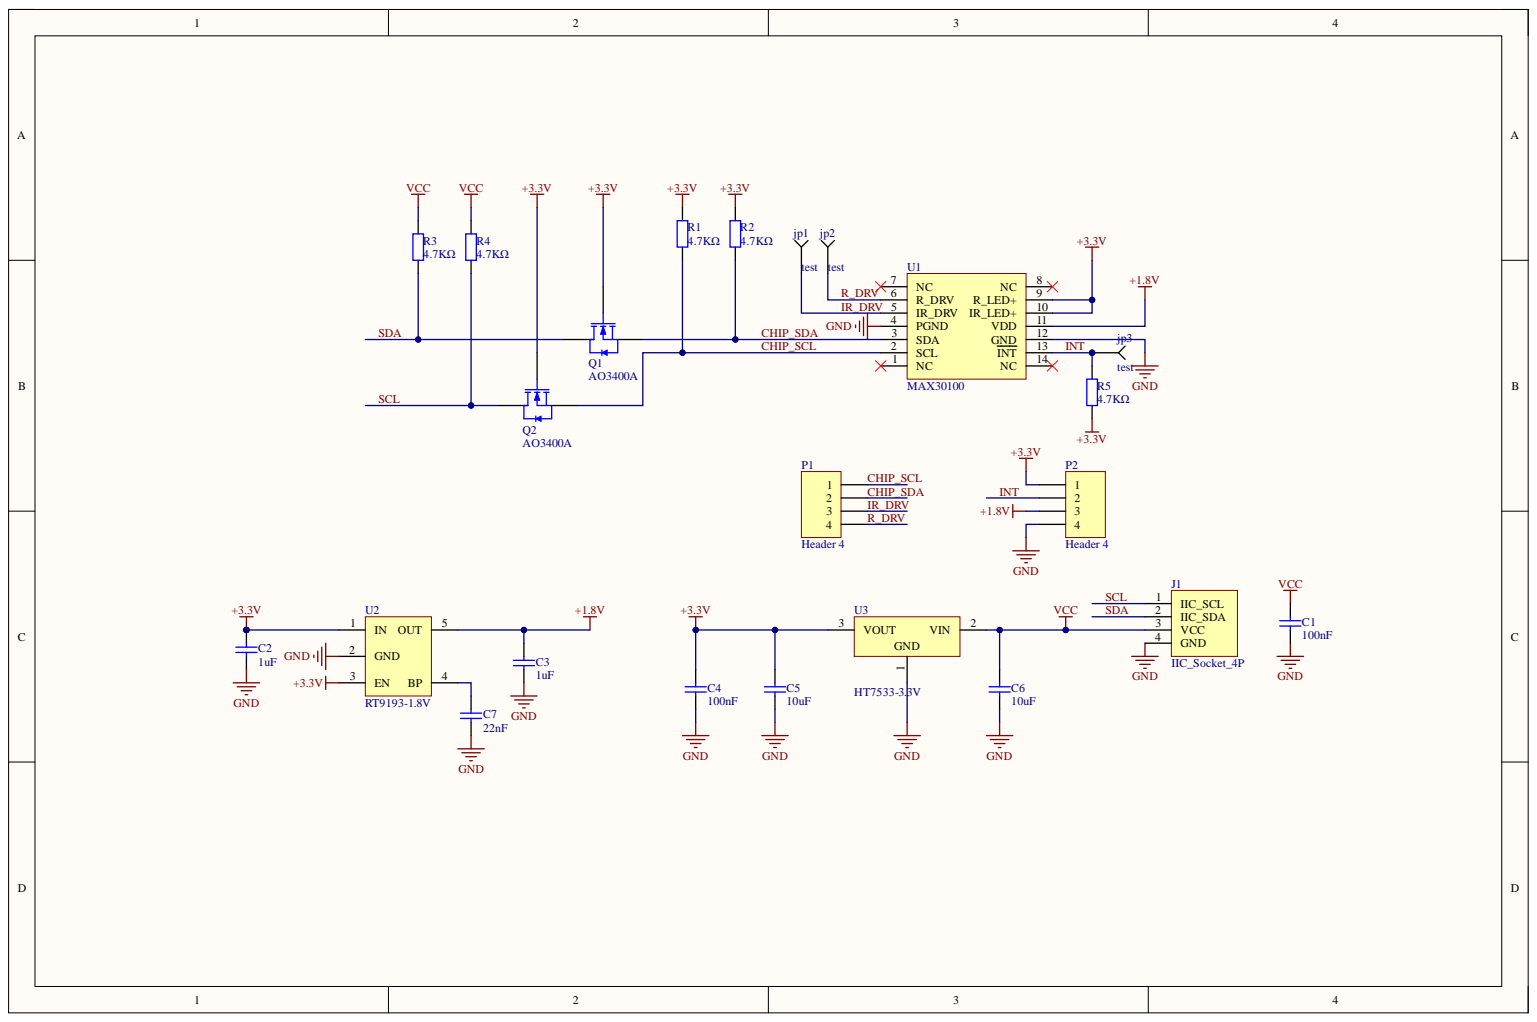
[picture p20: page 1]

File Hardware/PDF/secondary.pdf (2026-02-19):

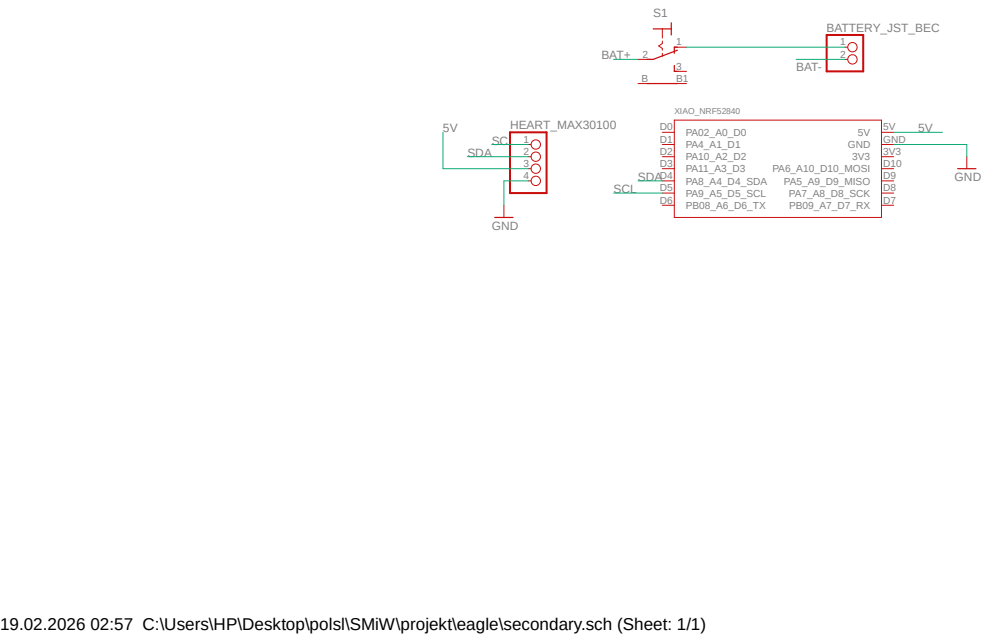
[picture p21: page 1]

19.02.2026 02:57 C:\Users\HP\Desktop\polsl\SMiW\projekt\eagle\secondary.sch (Sheet: 1/1)

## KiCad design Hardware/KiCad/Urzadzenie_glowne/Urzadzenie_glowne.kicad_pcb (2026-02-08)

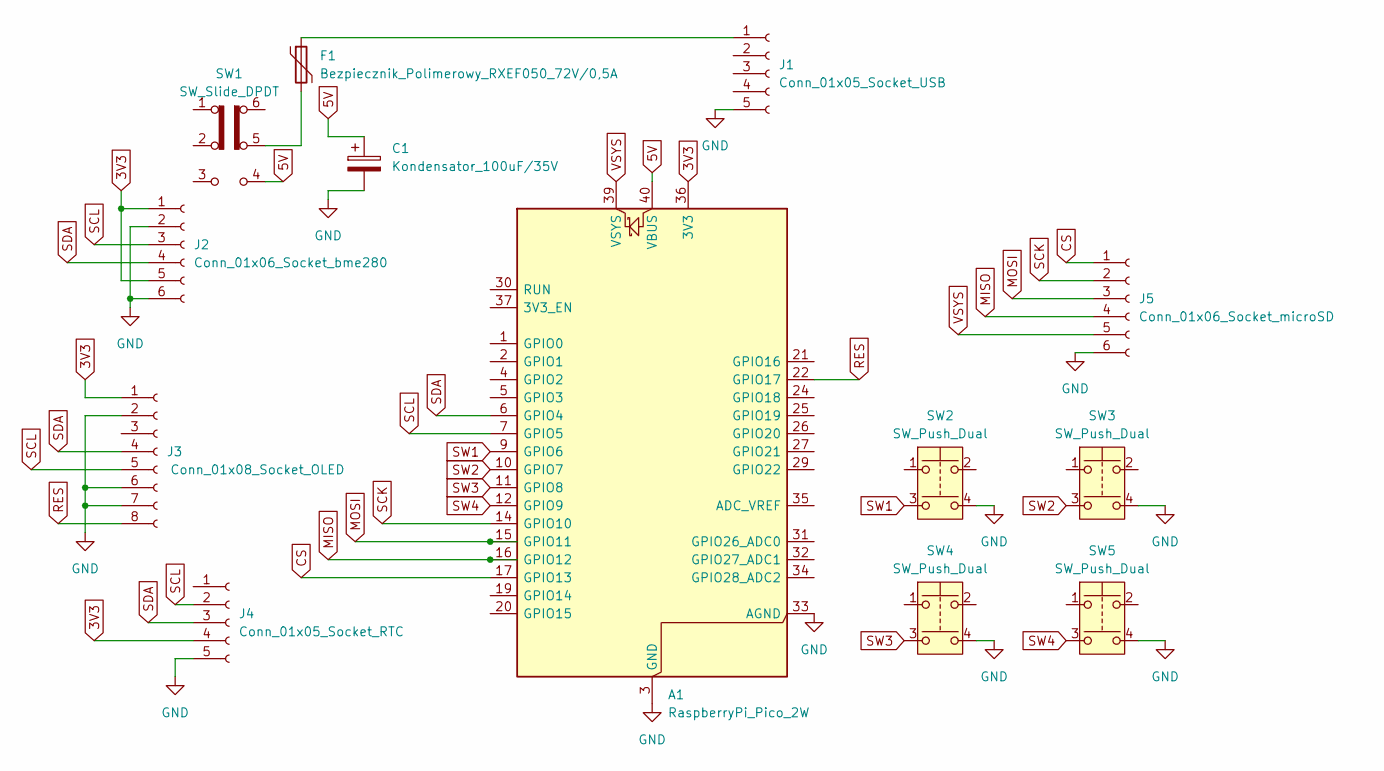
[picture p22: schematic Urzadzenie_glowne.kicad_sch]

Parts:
A1: RaspberryPi_Pico_2W; RaspberryPi_Pico_W_SMD_HandSolder
C1: Kondensator_100uF/35V; CP_Radial_D6.3mm_P2.50mm
F1: Bezpiecznik_Polimerowy_RXEF050_72V/0,5A; Fuse_Littelfuse-LVR100
J1: Conn_01x05_Socket_USB; PinSocket_1x05_P2.54mm_Vertical
J2: Conn_01x06_Socket_bme280; PinSocket_1x06_P2.54mm_Vertical
J3: Conn_01x08_Socket_OLED; PinSocket_1x08_P2.54mm_Vertical
J4: Conn_01x05_Socket_RTC; PinSocket_1x05_P2.54mm_Vertical
J5: Conn_01x06_Socket_microSD; PinSocket_1x06_P2.54mm_Vertical
SW1: SW_Slide_DPDT; SW_DPDT_CK_JS202011JCQN
SW2, SW3, SW4, SW5: SW_Push_Dual; SW_DIP_SPSTx02_Slide_6.7x6.64mm_W7.62mm_P2.54mm_LowProfile

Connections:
3V3: A1.36 (3V3), J2.1 (VCC), J2.5 (CSB), J3.1 (VCC), J4.4 (VCC)
5V: A1.40 (VBUS), C1.1, SW1.4 (A)
CS: A1.17 (GPIO13), J5.1 (CS)
GND: A1.3 (GND), A1.8 (GND), A1.13 (GND), A1.18 (GND), A1.23 (GND), A1.28 (GND), A1.33 (AGND), A1.38 (GND), C1.2, J1.5 (GND), J2.2 (GND), J2.6 (SDO), J3.2 (GND), J3.6 (CS), J3.7 (D/C), J4.5 (GND), J5.6 (GND), SW2.4, SW3.4, SW4.4, SW5.4
MISO: A1.16 (GPIO12), J5.4 (MISO)
MOSI: A1.15 (GPIO11), J5.3 (MOSI)
unnamed: F1.2, SW1.5 (B)
unnamed: F1.1, J1.1 (5V)
RES: A1.22 (GPIO17), J3.8 (RES)
SCK: A1.14 (GPIO10), J5.2 (SCK)
SCL: A1.7 (GPIO5), J2.3 (SCL), J3.5 (CLK), J4.2 (SCL)
SDA: A1.6 (GPIO4), J2.4 (SDA), J3.4 (DIN), J4.3 (SDA)
SW1: A1.9 (GPIO6), SW2.3
SW2: A1.10 (GPIO7), SW3.3
SW3: A1.11 (GPIO8), SW4.3
SW4: A1.12 (GPIO9), SW5.3
VSYS: A1.39 (VSYS), J5.5 (VCC)

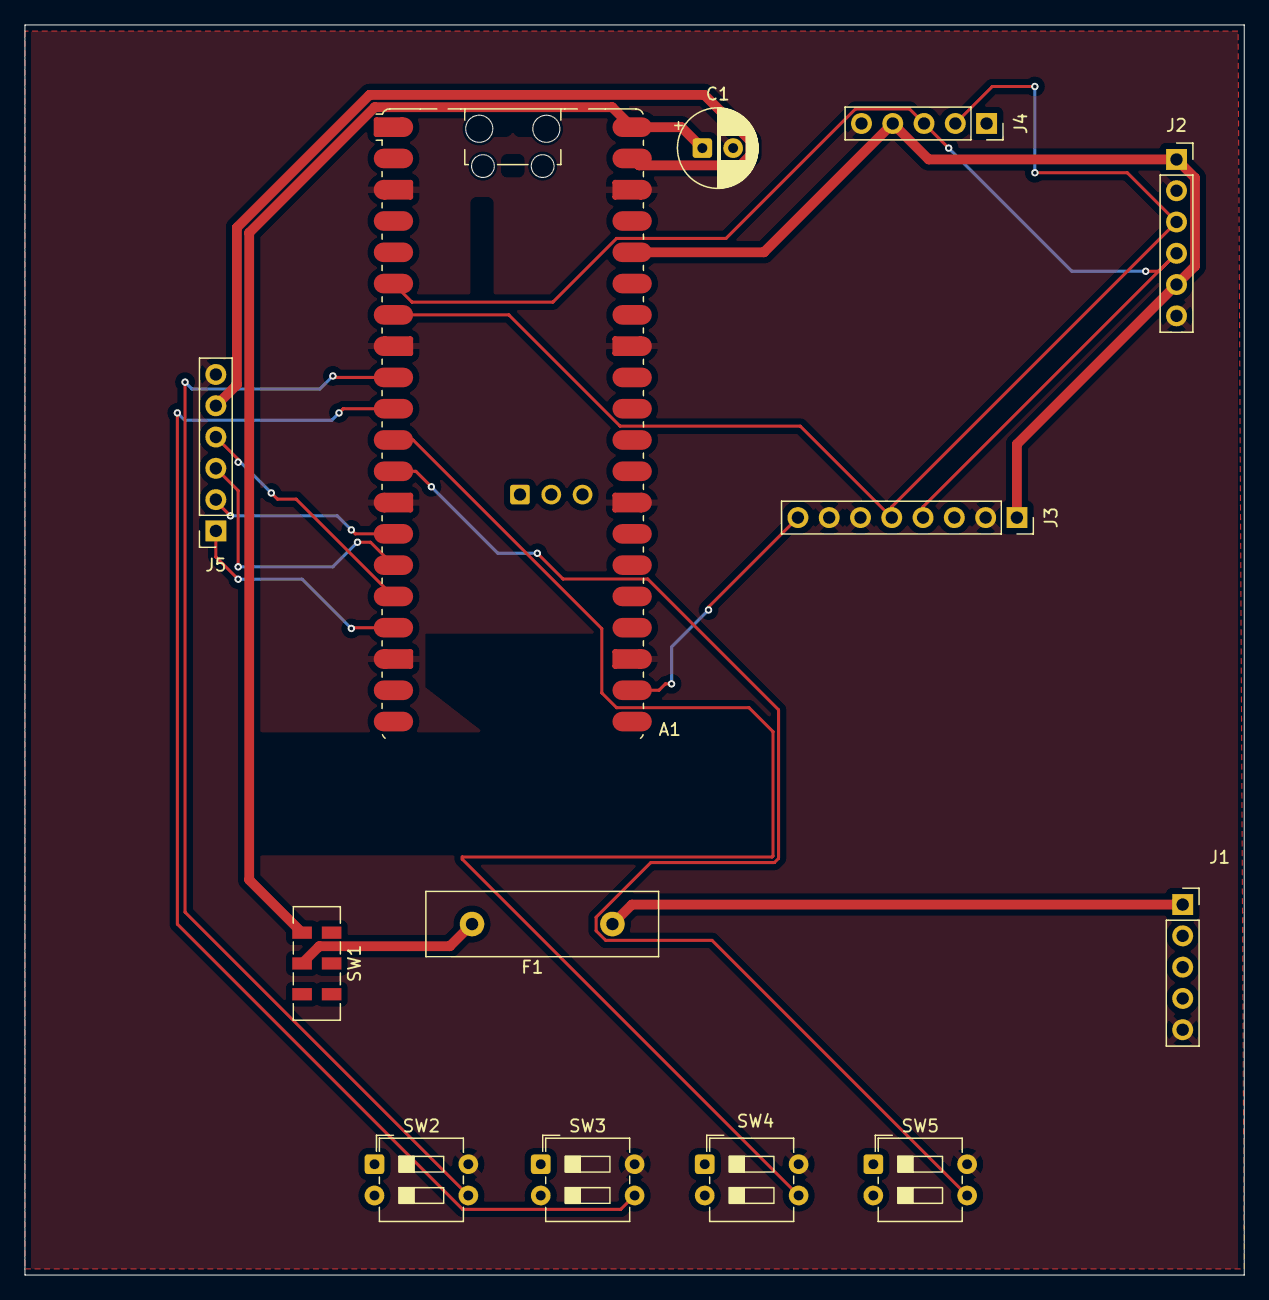
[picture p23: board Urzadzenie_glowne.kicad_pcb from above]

Board: 2 copper layers, 99.0 x 101.5 mm, 13 parts (0 on the bottom side), 17 nets.

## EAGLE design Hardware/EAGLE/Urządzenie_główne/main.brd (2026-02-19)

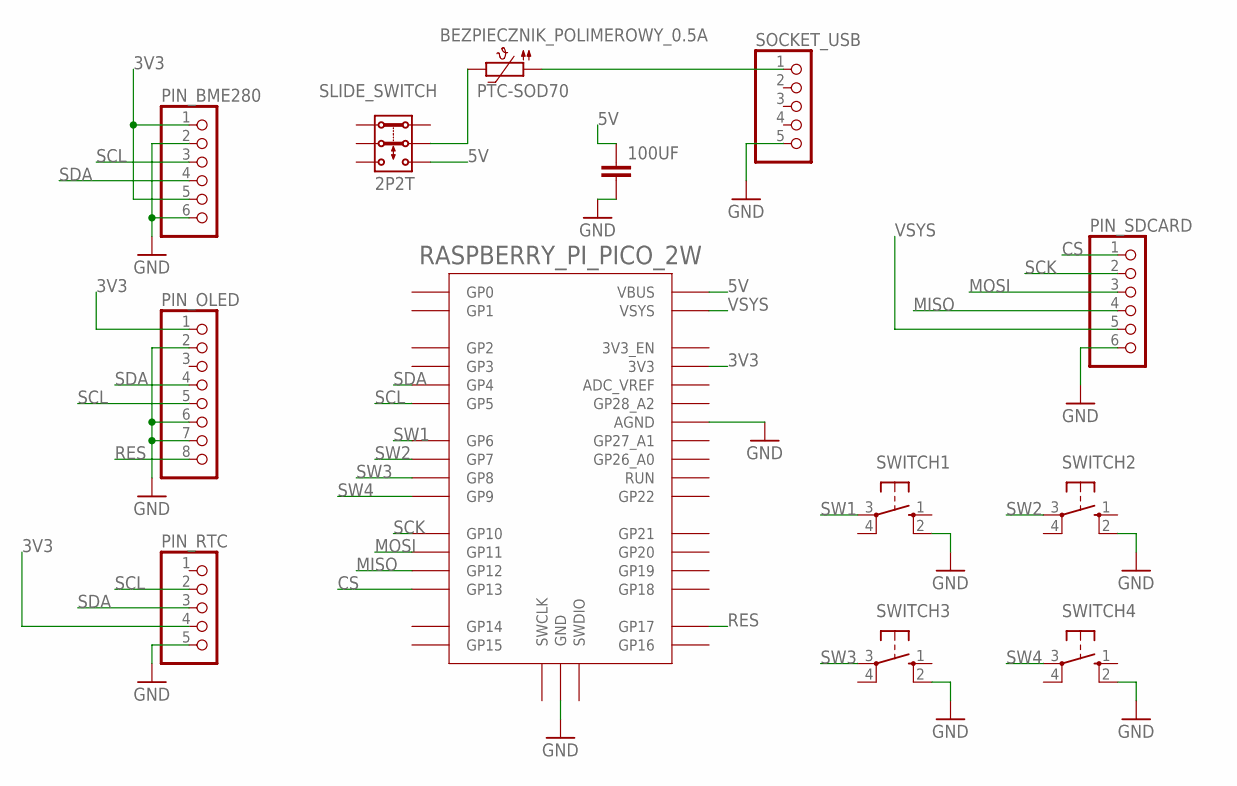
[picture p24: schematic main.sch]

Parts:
100UF: C2,5-3; C2.5-3
BEZPIECZNIK_POLIMEROWY_0.5A: PTC-SOD70; SOD70
PIN_BME280: PINHD-1X6; 1X06
PIN_OLED: PINHD-1X8; 1X08
PIN_RTC: PINHD-1X5; 1X05
PIN_SDCARD: PINHD-1X6; 1X06
RASPBERRY_PI_PICO_2W: RPI_PICO-TH; RPI_PICO_TH
SLIDE_SWITCH: 2P2T
SOCKET_USB: PINHD-1X5; 1X05
SWITCH1, SWITCH2, SWITCH3, SWITCH4: 10-XX; B3F-10XX

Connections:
3V3: PIN_BME280.1, PIN_BME280.5, PIN_OLED.1, PIN_RTC.4, RASPBERRY_PI_PICO_2W.3V3
5V: 100UF.1, RASPBERRY_PI_PICO_2W.VBUS, SLIDE_SWITCH.3.1
CS: PIN_SDCARD.1, RASPBERRY_PI_PICO_2W.GP13
GND: 100UF.2, PIN_BME280.2, PIN_BME280.6, PIN_OLED.2, PIN_OLED.6, PIN_OLED.7, PIN_RTC.5, PIN_SDCARD.6, RASPBERRY_PI_PICO_2W.AGND, RASPBERRY_PI_PICO_2W.GND@1 (GND), RASPBERRY_PI_PICO_2W.GND@2 (GND), RASPBERRY_PI_PICO_2W.GND@3 (GND), RASPBERRY_PI_PICO_2W.GND@4 (GND), RASPBERRY_PI_PICO_2W.GND@5 (GND), RASPBERRY_PI_PICO_2W.GND@6 (GND), RASPBERRY_PI_PICO_2W.GND@7 (GND), RASPBERRY_PI_PICO_2W.GND@8 (GND), SOCKET_USB.5, SWITCH1.2 (S1), SWITCH2.2 (S1), SWITCH3.2 (S1), SWITCH4.2 (S1)
MISO: PIN_SDCARD.4, RASPBERRY_PI_PICO_2W.GP12
MOSI: PIN_SDCARD.3, RASPBERRY_PI_PICO_2W.GP11
unnamed: BEZPIECZNIK_POLIMEROWY_0.5A.1, SOCKET_USB.1
unnamed: BEZPIECZNIK_POLIMEROWY_0.5A.2, SLIDE_SWITCH.2.1
RES: PIN_OLED.8, RASPBERRY_PI_PICO_2W.GP17
SCK: PIN_SDCARD.2, RASPBERRY_PI_PICO_2W.GP10
SCL: PIN_BME280.3, PIN_OLED.5, PIN_RTC.2, RASPBERRY_PI_PICO_2W.GP5
SDA: PIN_BME280.4, PIN_OLED.4, PIN_RTC.3, RASPBERRY_PI_PICO_2W.GP4
SW1: RASPBERRY_PI_PICO_2W.GP6, SWITCH1.3
SW2: RASPBERRY_PI_PICO_2W.GP7, SWITCH2.3
SW3: RASPBERRY_PI_PICO_2W.GP8, SWITCH3.3
SW4: RASPBERRY_PI_PICO_2W.GP9, SWITCH4.3
VSYS: PIN_SDCARD.5, RASPBERRY_PI_PICO_2W.VSYS

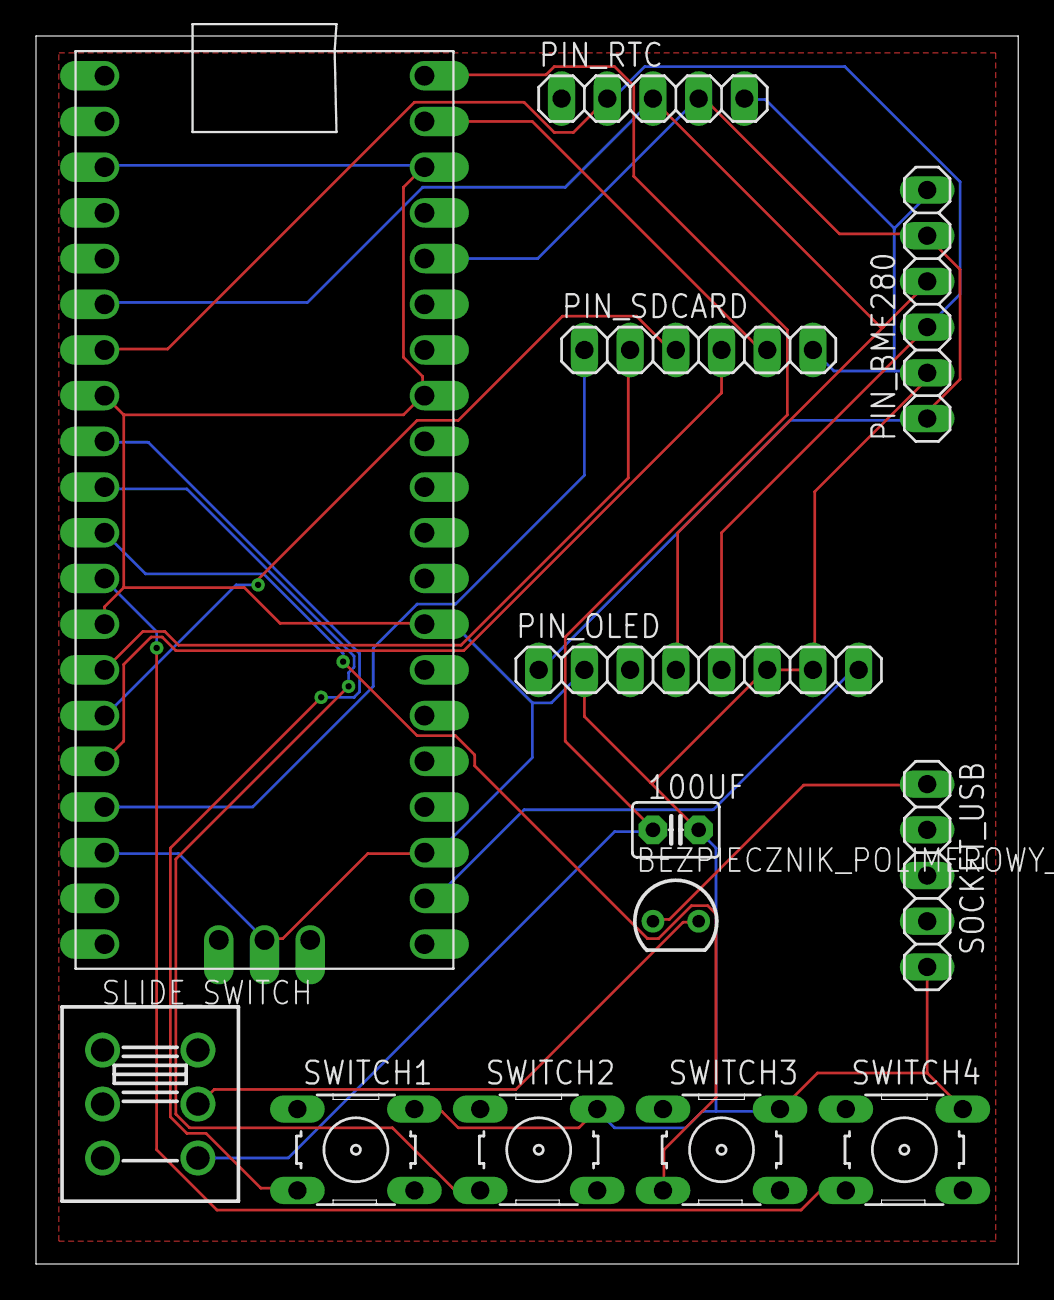
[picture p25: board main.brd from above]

Board: 2 copper layers, 54.6 x 68.2 mm, 13 parts (0 on the bottom side), 17 nets.

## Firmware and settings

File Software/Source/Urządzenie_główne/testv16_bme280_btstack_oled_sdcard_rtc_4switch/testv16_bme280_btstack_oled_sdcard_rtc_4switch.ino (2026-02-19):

#include <Wire.h>
#include <SPI.h>
#include <SD.h>
#include <Adafruit_Sensor.h>
#include <Adafruit_BME280.h>
#include <Adafruit_GFX.h>
#include <Adafruit_SSD1306.h>
#include <RTClib.h>
#include <btstack.h> 



const char* target_name = "XIAO_Health_Native";
const uint16_t target_service_uuid = 0xFF00;
const uint16_t target_char_uuid    = 0xFF01;

static btstack_packet_callback_registration_t hci_event_callback_registration;
static hci_con_handle_t connection_handle = HCI_CON_HANDLE_INVALID;
static gatt_client_notification_t notification_listener;

static gatt_client_service_t found_service;
static gatt_client_characteristic_t found_char;
static bool service_found = false;
static bool char_found = false;
static bool is_subscribed = false;


volatile int global_hr = 0;
volatile int global_spo2 = 0;
bool bleConnected = false;


#define I2C_SDA_PIN 4
#define I2C_SCL_PIN 5
#define OLED_RESET  17


#define SD_SCK  10
#define SD_MOSI 11
#define SD_MISO 12
#define SD_CS   13


#define BTN1_PIN 6
#define BTN2_PIN 7
#define BTN3_PIN 8
#define BTN4_PIN 9

#define BME_ADDR    0x76 
#define OLED_ADDR   0x3C

Adafruit_SSD1306 display(128, 64, &Wire, OLED_RESET);
Adafruit_BME280 bme;
RTC_DS3231 rtc;

uint32_t tsLastReport = 0;
uint32_t tsLastLog = 0;
const long REPORT_PERIOD = 100; 
const long LOG_PERIOD    = 60000; 

bool sdStatus = false;
int currentMode = 1; 


static void packet_handler(uint8_t packet_type, uint16_t channel, uint8_t *packet, uint16_t size);
static void gatt_event_handler(uint8_t packet_type, uint16_t channel, uint8_t *packet, uint16_t size);
static void on_characteristics_discovered(uint8_t packet_type, uint16_t channel, uint8_t *packet, uint16_t size);
static void on_services_discovered(uint8_t packet_type, uint16_t channel, uint8_t *packet, uint16_t size);

void setup() {
  Serial.begin(115200);

  pinMode(BTN1_PIN, INPUT_PULLUP);
  pinMode(BTN2_PIN, INPUT_PULLUP);
  pinMode(BTN3_PIN, INPUT_PULLUP);
  pinMode(BTN4_PIN, INPUT_PULLUP);

  Wire.setSDA(I2C_SDA_PIN);
  Wire.setSCL(I2C_SCL_PIN);
  Wire.begin();
  delay(1000);


  if(!display.begin(SSD1306_SWITCHCAPVCC, OLED_ADDR)) {
    Serial.println(F("OLED failed"));
    for(;;);
  }
  display.clearDisplay();
  display.setTextColor(SSD1306_WHITE);
  display.setTextSize(1);
  display.setCursor(0,0);
  display.println("Init Components...");
  display.display();


  if (!bme.begin(BME_ADDR)) {
    Serial.println("BME280 not found!");
    display.println("BME Fail!");
    display.display();
  }


  if (!rtc.begin()) {
    Serial.println("RTC not found");
    display.println("RTC Fail!");
    display.display();
    while(1);
  }
  if (rtc.lostPower()) {
    rtc.adjust(DateTime(F(__DATE__), F(__TIME__)));
  }


  SPI1.setSCK(SD_SCK);
  SPI1.setTX(SD_MOSI);
  SPI1.setRX(SD_MISO);
  if (!SD.begin(SD_CS, SPI1)) {
    Serial.println("SD Mount Failed!");
    display.println("SD Fail!"); 
    sdStatus = false;
  } 
  else {
    Serial.println("SD Mounted Successfully");
    sdStatus = true;
    if (!SD.exists("datalog.txt")) {
      File dataFile = SD.open("datalog.txt", FILE_WRITE);
      if (dataFile) {
        dataFile.println("Timestamp, Temp, Hum, Press, HR, SpO2");
        dataFile.close();
      }
    }
  }


  display.println("Init Bluetooth...");
  display.display();
  
  l2cap_init();
  gatt_client_init();
  sm_init();
  sm_set_io_capabilities(IO_CAPABILITY_NO_INPUT_NO_OUTPUT);

  hci_event_callback_registration.callback = &packet_handler;
  hci_add_event_handler(&hci_event_callback_registration);

  hci_power_control(HCI_POWER_ON);
  // --------------------

  delay(1000);
  display.clearDisplay();
}

void loop() {

  delay(10); 

  unsigned long currentMillis = millis();
  

  if (currentMillis - tsLastReport > REPORT_PERIOD) {
    DateTime now = rtc.now();
    float t = bme.readTemperature();
    float h = bme.readHumidity();
    float p = bme.readPressure() / 100.0F;
    
    if (digitalRead(BTN1_PIN) == LOW)      currentMode = 1;
    else if (digitalRead(BTN2_PIN) == LOW) currentMode = 2;
    else if (digitalRead(BTN3_PIN) == LOW) currentMode = 3;
    else if (digitalRead(BTN4_PIN) == LOW) currentMode = 4;
    
    updateScreen(now, t, h, p, sdStatus, currentMode);
    tsLastReport = currentMillis;
  }


  if (currentMillis - tsLastLog > LOG_PERIOD) {
    DateTime now = rtc.now();
    float t = bme.readTemperature();
    float h = bme.readHumidity();
    float p = bme.readPressure() / 100.0F;

    logData(now, t, h, p, global_hr, global_spo2);
    tsLastLog = currentMillis;
  }
}

void logData(DateTime dt, float t, float h, float p, int hr, int spo2) {
  if (!sdStatus) return;

  digitalWrite(LED_BUILTIN, HIGH);
  File dataFile = SD.open("datalog.txt", FILE_WRITE);
  if (dataFile) {
    dataFile.print(dt.year(), DEC); dataFile.print('/');
    dataFile.print(dt.month(), DEC); dataFile.print('/');
    dataFile.print(dt.day(), DEC);
    dataFile.print(" ");
    
    dataFile.print(dt.hour(), DEC); dataFile.print(':');
    dataFile.print(dt.minute(), DEC); dataFile.print(':');
    dataFile.print(dt.second(), DEC); dataFile.print(", ");
    
    dataFile.print(t); dataFile.print(", ");
    dataFile.print(h); dataFile.print(", ");
    dataFile.print(p); dataFile.print(", ");
    dataFile.print(hr); dataFile.print(", ");
    dataFile.println(spo2);
    
    dataFile.close();
    Serial.println("Log Saved");
  } else {
    sdStatus = false; 
  }
  digitalWrite(LED_BUILTIN, LOW);
}

void updateScreen(DateTime now, float t, float h, float p, bool sdOk, int mode) {
  display.clearDisplay();
  if (mode == 4) { display.display(); return; }

  display.setTextColor(SSD1306_WHITE);
  
  if (mode == 1) { // CLOCK
    display.setTextSize(1);
    display.setCursor(30, 0);
    if(now.day() < 10) display.print('0');
    display.print(now.day()); display.print('/');
    if(now.month() < 10) display.print('0');
    display.print(now.month()); display.print('/');
    display.print(now.year());

    display.setTextSize(2);
    display.setCursor(18, 25);
    if(now.hour() < 10) display.print('0');
    display.print(now.hour()); display.print(':');
    if(now.minute() < 10) display.print('0');
    display.print(now.minute());
    
    display.print(':');
    if(now.second() < 10) display.print('0');
    display.print(now.second());
  }
  else if (mode == 2) { 

    display.setTextSize(1);
    display.setCursor(0,0);
    if(bleConnected) display.print("Connected");
    else display.print("Searching...");


    display.drawLine(0, 10, 128, 10, SSD1306_WHITE);


    display.setTextSize(2);
    display.setCursor(0, 18);
    display.print("HR: ");
    if(global_hr > 0) display.print(global_hr);
    else display.print("--");
    display.setTextSize(1);
    display.print(" bpm");


    display.setTextSize(2);
    display.setCursor(0, 42);
    display.print("O2: ");
    if(global_spo2 > 0) display.print(global_spo2);
    else display.print("--");
    display.setTextSize(1);
    display.print(" %");
  }
  else if (mode == 3) { 
    display.setTextSize(1);
    display.setCursor(0, 0);
    if(now.day() < 10) display.print('0');
    display.print(now.day()); display.print('/');
    if(now.month() < 10) display.print('0');
    display.print(now.month()); 

    display.setCursor(80, 0);
    if(sdOk) display.print("SD ");
    if(bleConnected) display.print("BT");
    else display.print("--");

    display.setCursor(0, 12);
    display.setTextSize(2);
    if(now.hour() < 10) display.print('0');
    display.print(now.hour()); display.print(':');
    if(now.minute() < 10) display.print('0');
    display.print(now.minute());

    display.drawLine(0, 30, 128, 30, SSD1306_WHITE);


    display.setTextSize(1);
    display.setCursor(0, 34);
    display.print("T: "); display.print(t, 1);
    display.setCursor(0, 44);
    display.print("H: "); display.print(h, 0); display.print("%");
    display.setCursor(0, 54);
    display.print("P: "); display.print(p, 0);

    display.drawLine(64, 30, 64, 64, SSD1306_WHITE);


    display.setCursor(68, 34);
    display.print("HR: "); 
    if(global_hr > 0) display.print(global_hr);
    else display.print("--");

    display.setCursor(68, 44);
    display.print("O2: "); 
    if(global_spo2 > 0) { display.print(global_spo2); display.print("%"); }
    else display.print("--");
  }

  display.display();
}



static void gatt_event_handler(uint8_t packet_type, uint16_t channel, uint8_t *packet, uint16_t size) {
  if (packet_type != HCI_EVENT_PACKET) return;
  
  if (hci_event_packet_get_type(packet) == GATT_EVENT_NOTIFICATION) {
    const uint8_t *data = gatt_event_notification_get_value(packet);
    uint16_t length = gatt_event_notification_get_value_length(packet);

    if (length == 2) {
       global_hr = data[0];
       global_spo2 = data[1];
    }
  }
}

static void on_characteristics_discovered(uint8_t packet_type, uint16_t channel, uint8_t *packet, uint16_t size) {
  if (packet_type != HCI_EVENT_PACKET) return;
  uint8_t event = hci_event_packet_get_type(packet);

  if (event == GATT_EVENT_CHARACTERISTIC_QUERY_RESULT) {
    gatt_client_characteristic_t temp_char;
    gatt_event_characteristic_query_result_get_characteristic(packet, &temp_char);

    if (temp_char.uuid16 == target_char_uuid) {
      found_char = temp_char;
      char_found = true;
    }
  } 
  else if (event == GATT_EVENT_QUERY_COMPLETE) {
    if (char_found && !is_subscribed) {
      Serial.println("FORCING SUBSCRIPTION...");
      

      uint16_t cccd_handle = found_char.value_handle + 1;
      uint8_t enable_data[] = {0x01, 0x00};
      
      gatt_client_write_characteristic_descriptor_using_descriptor_handle(
          packet_handler, 
          connection_handle, 
          cccd_handle, 
          2, 
          enable_data
      );

      
      is_subscribed = true;
    }
  }
}

static void on_services_discovered(uint8_t packet_type, uint16_t channel, uint8_t *packet, uint16_t size) {
  if (packet_type != HCI_EVENT_PACKET) return;
  uint8_t event = hci_event_packet_get_type(packet);

  if (event == GATT_EVENT_SERVICE_QUERY_RESULT) {
    gatt_client_service_t service;
    gatt_event_service_query_result_get_service(packet, &service);
    if (service.uuid16 == target_service_uuid) {
      found_service = service;
      service_found = true;
    }
  } 
  else if (event == GATT_EVENT_QUERY_COMPLETE) {
    if (service_found) {
      gatt_client_discover_characteristics_for_service(&on_characteristics_discovered, connection_handle, &found_service);
    }
  }
}

static void packet_handler(uint8_t packet_type, uint16_t channel, uint8_t *packet, uint16_t size) {
  if (packet_type != HCI_EVENT_PACKET) return;
  uint8_t event = hci_event_packet_get_type(packet);

  switch (event) {
    case BTSTACK_EVENT_STATE:
      if (btstack_event_state_get_state(packet) == HCI_STATE_WORKING) {
        gap_set_scan_parameters(0, 0x0030, 0x0030);
        gap_start_scan();
      }
      break;

    case GAP_EVENT_ADVERTISING_REPORT: {
      uint8_t event_type = gap_event_advertising_report_get_advertising_event_type(packet);
      if (event_type == 0 || event_type == 1) { 
        bd_addr_t address;
        gap_event_advertising_report_get_address(packet, address);
        uint8_t length = gap_event_advertising_report_get_data_length(packet);
        const uint8_t *data = gap_event_advertising_report_get_data(packet);
        
        int i = 0;
        while (i < length) {
          uint8_t len = data[i];
          if (len == 0) break;
          uint8_t type = data[i+1];
          if (type == 0x09 || type == 0x08) { 
            char name_buffer[32];
            memset(name_buffer, 0, 32);
            memcpy(name_buffer, &data[i+2], (len - 1) > 30 ? 30 : (len - 1));
            
            if (strcmp(name_buffer, target_name) == 0) {
              gap_stop_scan();
              gap_connect(address, (bd_addr_type_t)gap_event_advertising_report_get_address_type(packet));
              return;
            }
          }
          i += len + 1;
        }
      }
      break;
    }

    case HCI_EVENT_LE_META:
      if (hci_event_le_meta_get_subevent_code(packet) == HCI_SUBEVENT_LE_CONNECTION_COMPLETE) {
        if (hci_subevent_le_connection_complete_get_status(packet) == 0) {
          connection_handle = hci_subevent_le_connection_complete_get_connection_handle(packet);
          bleConnected = true;
          
          service_found = false;
          char_found = false;
          is_subscribed = false;
          
          gatt_client_discover_primary_services_by_uuid16(on_services_discovered, connection_handle, target_service_uuid);
          gatt_client_listen_for_characteristic_value_updates(&notification_listener, &gatt_event_handler, connection_handle, NULL);
        } else {
          gap_start_scan();
        }
      }
      break;

    case HCI_EVENT_DISCONNECTION_COMPLETE:
      bleConnected = false;
      global_hr = 0;
      global_spo2 = 0;
      is_subscribed = false;
      gap_start_scan();
      break;
  }
}

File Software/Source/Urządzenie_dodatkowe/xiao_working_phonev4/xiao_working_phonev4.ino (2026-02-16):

#include <Wire.h>
#include "MAX30100_PulseOximeter.h"
#include <bluefruit.h>

#define LEDR 11
#define LEDG 12
#define LEDB 13

PulseOximeter pox;
uint32_t tsLastReport = 0;
bool sensorWorking = false;

const uint16_t CUSTOM_SERVICE_UUID = 0xFF00;
const uint16_t CUSTOM_CHAR_UUID    = 0xFF01;

BLEService        customService = BLEService(CUSTOM_SERVICE_UUID);
BLECharacteristic customChar    = BLECharacteristic(CUSTOM_CHAR_UUID);

void onBeatDetected() {

    digitalWrite(LEDG, LOW); delay(20); digitalWrite(LEDG, HIGH);
}

void setup() {
    pinMode(LEDR, OUTPUT); pinMode(LEDG, OUTPUT); pinMode(LEDB, OUTPUT);
    digitalWrite(LEDR, HIGH); digitalWrite(LEDG, HIGH); digitalWrite(LEDB, HIGH);

    Serial.begin(115200);
    

    if (!pox.begin()) {
        sensorWorking = false;
        digitalWrite(LEDR, LOW); 
    } else {
        sensorWorking = true;
        pox.setIRLedCurrent(MAX30100_LED_CURR_7_6MA);
        pox.setOnBeatDetectedCallback(onBeatDetected);
        digitalWrite(LEDG, LOW); delay(200); digitalWrite(LEDG, HIGH);
    }

    Bluefruit.begin();
    Bluefruit.setName("XIAO_Health_Native");

    customService.begin();


    customChar.setProperties(CHR_PROPS_NOTIFY | CHR_PROPS_READ);

    customChar.setPermission(SECMODE_OPEN, SECMODE_OPEN);

    
    customChar.setFixedLen(2); 
    customChar.begin();

    Bluefruit.Advertising.addFlags(BLE_GAP_ADV_FLAGS_LE_ONLY_GENERAL_DISC_MODE);
    Bluefruit.Advertising.addService(customService);
    Bluefruit.Advertising.addName();
    Bluefruit.Advertising.start(0); 
}

void loop() {
    if (sensorWorking) pox.update();

    if (millis() - tsLastReport > 1000) {
        uint8_t bpm = 0;
        uint8_t spo2 = 0;

        if (sensorWorking) {
            bpm = (uint8_t)pox.getHeartRate();
            spo2 = pox.getSpO2();
        } else {
            bpm = 65; spo2 = 98; 
        }

        if (Bluefruit.connected()) {
            if (customChar.notifyEnabled()) {
                uint8_t packet[2] = {bpm, spo2};
                customChar.notify(packet, 2);
                Serial.print("Sent -> HR:"); Serial.print(bpm);
                Serial.print(" SpO2:"); Serial.println(spo2);
            } else {
                Serial.println("Connected - Waiting for Pico to Subscribe...");
            }
        }
        tsLastReport = millis();
    }
}

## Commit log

2026-02-19 fixed according to instructions
    [Urzadzenie_glowne.kicad_pcb, Urzadzenie_glowne.kicad_sch, dodatkowe.kicad_pcb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]
2026-02-19 added old board pdf
